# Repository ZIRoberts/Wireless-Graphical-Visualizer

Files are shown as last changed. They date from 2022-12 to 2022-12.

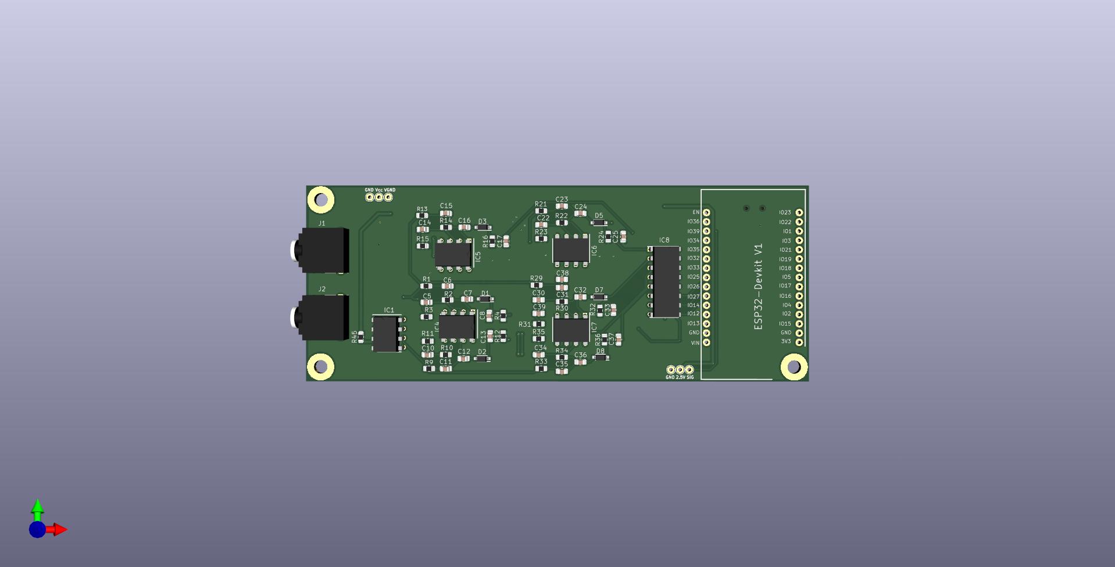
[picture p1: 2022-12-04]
Graphic Equalizer/Graphic_Equalzier_Schematic.jpg

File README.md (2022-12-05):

# Wireless-Graphical-Visualizer
Maintain all documents relating to the creation of the Realtime Wireless Graphical Equalizer.  All symbols, schematics, footprints, and board layouts are designed in KiCad.

Top Orth

# Overview

There is a single board in this sytem and it is broken up into three sections represented by their own respeitive schematic sheet. The first section is the board's inputs. This includes the audio input, power input and regulation, and the audio isolation buffer. Audio is input by a standard 3.5 mm audio cable through one of the two linked audio jacks and enters the system by passing through the unity gain isolation buffer. The two audio jacks are to allow for the user to pass the audio through the device to a speaker without any disortion caused by the filters. Power is inputed by a standard USB Type-B mini cable. There are two 2.5 V linear regulators connected directly to the input line. One serves as a virtual ground to refence the audio signal two later in on in the single supply band pass filters. The other is used on the output of the filters as a voltage calmp to ensure the microcontroller will not get damaged due to an unexpectedly large singal being passed through the filters.

The second section is the bandpass filter section. There are 8 multiple feedback band pass filters. Multifple feed back band pass fitlers were selected based on their low componet cost, moderate gain, and able to handle to filter a signal up to around 5 Q. The 8 bands are tuned to the fallowing frequnecies: 160, 250, 400, 800, 1000, 2500, 4000, and 6500 Hz. The frequncies are filted through their specified filter, have their DC offset stripped, pass through a half-wave rectifer and a 22 uF capacitor to keep the signal from instantly dissapating. This output is then passed through a voltage clamp consiting of a 2.5 V linear regulator and a 500 mV foward voltage diode to prevent the output signal from passive above 3 V as any input above 3V3 would fry the microcontroller. 

The third section is the microcontoller and multiplexor. This section cotnains the connections for the selected ESP32 microcontroller along with the mux. The mux is used to select which of the 8 filtered outputs would be read in by the microcontroller. The MCU used for this project is the ESP32 by Espressiff Systems. This microcontroller was sekected because it was of appropriate size, had appropriate pin count, built in wireless communication, compatablity with Arduino libraries, and the creator already had experience using this family of microcontrollers. This sheet also holds the diodes used for the voltage clamp discribed on in the previous section.

A full list of electronic components can be found in the Bill of Materials.xlsx and images of the design can be found below.

# Schematic
## Aduio and Power Sheet
Input and power sheet
## Bandpass Filter Sheet
Band Pass filter stage
## Microcontroller sheet
microcontroller, mux, Vclamp

# PCB Layout
## Front Copper 
front copper
## Back Copper
Back copper

# 3D Renders
## Front Render
top render
## Bottom Render
bottom render

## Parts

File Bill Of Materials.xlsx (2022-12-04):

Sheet: Mouser
Part Type | Part # | val | Package | quanity per | quanity purchase | price purchase | price per board | Total | link
Audio Jack | SJ1-3523N | x |  | 2 | 4 | $0.74 | $1.48 | $2.96 | https://www.mouser.com/ProductDetail/CUI-Devices/SJ1-3523N?qs=WyjlAZoYn50aNl0vAhb3Tg%3D%3D
usb terminal | 10033526-N3212LF | x | smd | 1 | 5 | $0.77 | $0.77 | $3.85 | https://www.mouser.com/ProductDetail/Amphenol-FCI/10033526-N3212LF
Duel Op amp | TLV2372IP | x | dip 8 | 4 | 10 | $2.39 | $9.56 | $23.90 | https://www.mouser.com/ProductDetail/Texas-Instruments/TLV2372IP?qs=dQbkqP7qjabLXs2c4TTU4Q%3D%3D
Single op amp | TLV2371IP | x | dip 8 | 1 | 4 | $1.87 | $1.87 | $7.48 | https://www.mouser.com/ProductDetail/Texas-Instruments/TLV2371IP?qs=5WY7Uqh921z4LbFYVLVHkQ%3D%3D
mux | MAX4617CPE+ | x | dip 16 | 1 | 3 | $4.80 | $4.80 | $14.40 | https://www.mouser.com/ProductDetail/Maxim-Integrated/MAX4617CPE%2b
voltage reg | MCP1700T-2502E/TT | 2.5V | sot-23-3 | 2 | 6 | $0.41 | $0.82 | $2.46 | https://www.mouser.com/ProductDetail/Microchip-Technology/MCP1700T-2502E-TT?qs=fM4xO01eazNo%2FPEFFkh6Nw%3D%3D
IC Socket | 110-41-308-41-001000 | x | dip 8 | 5 | 10 | $0.56 | $2.80 | $5.60 | https://www.mouser.com/ProductDetail/Mill-Max/110-41-308-41-001000?qs=dvxwXVM4mZVj1CY1TePuww%3D%3D
female header | 15Fx1-254mm | x | header | 2 | 6 | $1.04 | $2.08 | $6.24 | https://www.mouser.com/ProductDetail/Gravitech/15Fx1-254mm?qs=Vxac6xGyzPnMG7UJxd5xkg%3D%3D
screw terminal | 1935161 | x | 1x10 | 2 | 2 | $0.49 | $0.98 | $0.98 | https://www.mouser.com/ProductDetail/Phoenix-Contact/1935161?qs=W3wJikR1%252BS6eKzfFl8Rbew%3D%3D
schottky diode | BAT54W-HG3-18 | 200 mv Vf | SOD-123-2 | 8 | 20 | $0.24 | $1.90 | $4.74 | https://www.mouser.com/ProductDetail/Vishay-Semiconductors/BAT54W-HG3-18?qs=BJlw7L4Cy79w8lzctLBe5g%3D%3D
schottky diode | MMBD101LT1G | 600 mv Vf | sot-23-3 | 8 | 20 | $0.20 | $1.59 | $3.98 | https://www.mouser.com/ProductDetail/ON-Semiconductor/MMBD101LT1G
Capacitor | C0805C103J5RACTU | .01u | 0805 | 12 | 30 | $0.05 | $0.55 | $1.38 | https://www.mouser.com/ProductDetail/KEMET/C0805C103J5RACTU?qs=Onq5MIl0ZjiJ615hCkQQ7A%3D%3D
Capacitor | 08055C203JAT4A | .02u | 0805 | 4 | 10 | $0.25 | $1.00 | $2.51 | https://www.mouser.com/ProductDetail/AVX/08055C203JAT4A?qs=ykEKLGTiBcxBcZNPbEjGfw%3D%3D | cheaper to double up on .01 u
Capacitor | 08055C104JAT2A | .1u | 0805 | 9 | 25 | $0.09 | $0.82 | $2.27 | https://www.mouser.com/ProductDetail/AVX/08055C104JAT2A?qs=rjW0lv%2FNY4O5UTQV%252BL9pEw%3D%3D
Capacitor | CL21B224KAFNNNG | .22u | 0805 | 5 | 15 | $0.03 | $0.17 | $0.51 | https://www.mouser.com/ProductDetail/Samsung-Electro-Mechanics/CL21B224KAFNNNG
Capacitor | CL21A106KPCLQNC | 10u | 0805 | 8 | 20 | $0.05 | $0.39 | $0.98 | https://www.mouser.com/ProductDetail/Samsung-Electro-Mechanics/CL21A106KPCLQNC?qs=j0anFx7zyhyh2SZCFuTXeg%3D%3D
Capacitor | GRM21BR61A226ME51L | 22u | 0805 | 8 | 20 | $0.13 | $1.06 | $2.64 | https://www.mouser.com/ProductDetail/Murata-Electronics/GRM21BR61A226ME51L?qs=GJ9CiehniqLndbYAzpHGvw%3D%3D
Capacitor | C0805C105K4RACTU | 1u | 0805 | 6 | 16 | $0.06 | $0.34 | $0.91 | https://www.mouser.com/ProductDetail/KEMET/C0805C105K4RACTU?qs=yrVqjCObULOefkidH6lLLQ%3D%3D
resistor | RC0805JR-100RL | 0 | 0805 | 20 | 100 | $0.01 | $0.30 | $1.50 | https://www.mouser.com/ProductDetail/YAGEO/RC0805JR-100RL?qs=fRxXYNj8ftFe%252BcsxoUmr4g%3D%3D
resistor | ERJ-P06F2700V | 267 | 0805 | 6 | 15 | $0.14 | $0.83 | $2.08 | https://www.mouser.com/ProductDetail/Panasonic/ERJ-P06F2700V?qs=iIVTEDlrHA0KQ7C%252Bd58SjQ%3D%3D
resistor | ERJ-P06F3000V | 301 | 0805 | 1 | 5 | $0.18 | $0.18 | $0.90 | https://www.mouser.com/ProductDetail/Panasonic/ERJ-P06F3000V?qs=iIVTEDlrHA3O1TU1AmFELg%3D%3D
resistor | ERJ-P06F3480V | 348 | 0805 | 1 | 4 | $0.18 | $0.18 | $0.72 | https://www.mouser.com/ProductDetail/Panasonic/ERJ-P06F3480V?qs=iIVTEDlrHA2Mos3Mjm8zhw%3D%3D
resistor | ERJ-P06F4020V | 402 | 0805 | 2 | 6 | $0.20 | $0.40 | $1.20 | https://www.mouser.com/ProductDetail/Panasonic/ERJ-P06F4020V
resistor | ERJ-P06F8060V | 806 | 0805 | 1 | 4 | $0.20 | $0.20 | $0.80 | https://www.mouser.com/ProductDetail/Panasonic/ERJ-P06F8060V
resistor | RC0805FR-101K2L | 1200 | 0805 | 1 | 4 | $0.10 | $0.10 | $0.40 | https://www.mouser.com/ProductDetail/YAGEO/RC0805FR-101K2L?qs=g6xwsc4j%252B%2FqKMlZ4Dwe6Dw%3D%3D
resistor | AC0805FR-7W2KL | 2000 | 0805 | 2 | 10 | $0.06 | $0.12 | $0.59 | https://www.mouser.com/ProductDetail/YAGEO/AC0805FR-7W2KL
resistor | ERJ-P06F4751V | 4750 | 0805 | 1 | 4 | $0.28 | $0.28 | $1.12 | https://www.mouser.com/ProductDetail/Panasonic/ERJ-P06F4751V?qs=iIVTEDlrHA1dktajbqD0%2FQ%3D%3D
resistor | ERJ-P06F4991V | 4990 | 0805 | 1 | 4 | $0.20 | $0.20 | $0.80 | https://www.mouser.com/ProductDetail/Panasonic/ERJ-P06F4991V?qs=sGAEpiMZZMtlubZbdhIBIK7FbVYKWV6WU1u7RLCIVSI%3D
resistor | RCS06036K04FKEA | 6040 | 0805 | 2 | 5 | $0.15 | $0.30 | $0.75 | https://www.mouser.com/ProductDetail/Vishay-Dale/RCS06036K04FKEA?qs=6AVTNucw1PVOKD11i3Bl8Q%3D%3D
resistor | ERJ-P06F7501V | 7500 | 0805 | 2 | 10 | $0.15 | $0.31 | $1.54 | https://www.mouser.com/ProductDetail/Panasonic/ERJ-P06F7501V
resistor | RC0805FR-1310KL | 10000 | 0805 | 2 | 10 | $0.03 | $0.06 | $0.31 | https://www.mouser.com/ProductDetail/YAGEO/RC0805FR-1310KL?qs=m6lXFsvg5e2DzD%2FscmphNQ%3D%3D
resistor | ERJ-6ENF2372V | 23700 | 0805 | 2 | 10 | $0.07 | $0.15 | $0.75 | https://www.mouser.com/ProductDetail/Panasonic/ERJ-6ENF2372V?qs=50QC8w71jAvtfOjSV7AQZw%3D%3D
resistor | CR0805-FX-3482ELF | 34800 | 0805 | 1 | 10 | $0.05 | $0.05 | $0.50 | https://www.mouser.com/ProductDetail/Bourns/CR0805-FX-3482ELF?qs=TYKCbaKwe1BX%252B2fT1xNjLQ%3D%3D
resistor | ERJ-6ENF3572V | 35700 | 0805 | 1 | 4 | $0.10 | $0.10 | $0.40 | https://www.mouser.com/ProductDetail/Panasonic/ERJ-6ENF3572V
resistor | ERJ-P06F4022V | 40200 | 0805 | 1 | 4 | $0.20 | $0.20 | $0.80 | https://www.mouser.com/ProductDetail/Panasonic/ERJ-P06F4022V?qs=iIVTEDlrHA1ZhEwjw363Sg%3D%3D
resistor | RC0805FR-1347K5L | 47500 | 0805 | 1 | 25 | $0.02 | $0.02 | $0.47 | https://www.mouser.com/ProductDetail/YAGEO/RC0805FR-1347K5L?qs=m6lXFsvg5e1D72C5kBh1CA%3D%3D
resistor | AC0805FR-7W49K9L | 49900 | 0805 | 2 | 10 | $0.06 | $0.12 | $0.59 | https://www.mouser.com/ProductDetail/YAGEO/AC0805FR-7W49K9L?qs=mQk0km4IMDeRJfAtVBkHxg%3D%3D
resistor | ERJ-UP3F5492V | 54900 | 0805 | 1 | 4 | $0.26 | $0.26 | $1.04 | https://www.mouser.com/ProductDetail/Panasonic/ERJ-UP3F5492V?qs=GedFDFLaBXFu8CUGA65Aag%3D%3D
resistor | AC0805FR-7W100KL | 100000 | 0805 | 8 | 20 | $0.08 | $0.67 | $1.68 | https://www.mouser.com/ProductDetail/YAGEO/AC0805FR-7W100KL?qs=mQk0km4IMDdDYiNYyM1r7w%3D%3D
resistor | RC0805FR-13200KL | 200k | 0805 | 3 | 10 | $0.04 | $0.14 | $0.45 | https://www.mouser.com/ProductDetail/YAGEO/RC0805FR-13200KL?qs=m6lXFsvg5e0hZfOOUQ%2FIgw%3D%3D
resistor | ERJ-P06F2553V | 255k | 0805 | 3 | 10 | $0.15 | $0.46 | $1.54 | https://www.mouser.com/ProductDetail/Panasonic/ERJ-P06F2553V?qs=iIVTEDlrHA22vnXhPU7c3w%3D%3D
resistor | ERJ-P06F3653V | 365k | 0805 | 1 | 4 | $0.18 | $0.18 | $0.72 | https://www.mouser.com/ProductDetail/Panasonic/ERJ-P06F3653V?qs=iIVTEDlrHA0ZFGDvIdekGA%3D%3D
resistor | RC0805FR-101ML | 1M | 0805 | 8 | 20 | $0.03 | $0.25 | $0.62 | https://www.mouser.com/ProductDetail/YAGEO/RC0805FR-101ML?qs=g6xwsc4j%252B%2FquvT%252BzGahIFg%3D%3D
 |  |  | Component | 162 | 538 |  |  | $8.00 | shipping
 |  |  |  |  |  |  | $39.04 | $118.08
 |  |  | resistor | 74
 |  |  | Caps | 52
Dev board | Esp32 S3 N8R8 |  |  |  | 2 | $15.00 |  | $30.00 | https://www.mouser.com/ProductDetail/Espressif-Systems/ESP32-S3-DevKitC-1-N8R8

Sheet: Led & PCB pricing
Item | price | description | link
LED | 25.99 | ws2812B 60 pix/m leds | https://www.amazon.com/BTF-LIGHTING-Individual-Addressable-300Pixels-Waterproof/dp/B088B9QWHT?s=hi
power supply | 23.99 | 5v 10 amp 50w power supply | https://www.amazon.com/ALITOVE-Transformer-Converter-5-5x2-1mm-100V-240V/dp/B0852HL336
PCB | 68.8 | PCB | https://www.digikey.com/en/resources/dkred
usb power cable | 5.14 | mcro type B calbe | https://www.amazon.com/Monoprice-10-Feet-Mini-B-Ferrite-105449/dp/B002KL8J8W
Solder | 5.93 | kester leaded solder | https://www.amazon.com/Kester-83-4000-0000-SN60PB40-Solder-Diameter/dp/B00068IJNQ
Flux | 9 | rosin flux | https://www.amazon.com/SRA-Rosin-Paste-Flux-135/dp/B008ZIV85A/ref=cm_cr_arp_d_product_top?ie=UTF8
Solder wick | 9.74 |  | https://www.amazon.com/NTE-Electronics-SW02-10-No-Clean-Blue-098/dp/B0195UVWJ8
Tweezers | 6 |  | https://www.amazon.com/Precision-Anti-Static-Electronics-Sodlering%EF%BC%8CJewelry-Laboratory/dp/B07ZBZ7MSF
total | 154.59
OVER ALL TOTAL | 272.667

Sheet: power consumption (amps)
Component | Current (mA) | Quanity | Total Current
Esp32 | 240 | 1 | 240
Mux | 0.01 | 1 | 0.01
Duel Amp | 1.1 | 6 | 6.6
Single Amp | 0.55 | 1 | 0.55
Voltage reg | 2 | 2 | 4
 |  | Typical | 251.16
 |  | Inrush current | 753.48
 | USB TERMINAL SUPPLY |  | 1800

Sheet: Component mapping
Resistor |  |  |  | Capacitor |  |  | Diode |  |  |  | IC |  |  | Other
Value | Quanity | Mapping |  | Value | Quanity | Mapping | Value | Quanity | Mapping |  | Part | Quanity | Mapping | Type | Quanity | Mapping
0 | 20 | r5/r6 |  | .01u | 12 | C5,C6,C10,C11, C8,C13,C17,C21, C25,C29,C33,C37 | 200 mv Vf | 8 | D1, D2, D3, D4, D5, D6, D7, D8 |  | Single op amp | 4 | IC4, IC5, IC6, IC7 | Audio Jack | 2 | j1, j2
270 | 3 | R3, R23, R31 |  | .02u | 4 | C14,C15,C19,C20 | 600 mv Vf | 8 | D9, D10, D11, D12, D13, D14, D15, D16 |  | Duel Op amp | 1 | IC1 | usb terminal | 1 | j3
301 | 1 | R15 |  | .1u | 9 | c9, C22, c23, c26,c27, C30,C31,C38,C39 |  |  |  |  | Vreg 2.5 V | 2 | IC2, IC3 | 8 pin socket | 5 | IC1, IC4, IC5, IC6, IC7
348 | 1 | R11 |  | 10u | 8 | C7, C12, C16, C20, C24, C28, C32, C36 |  |  |  |  | Mux | 1 | IC8 | 16 pin socket | 1 | IC8
402 | 2 | R27, R35 |  | 22u | 8 | C7, C12, C16, C20, C24, C28, C32, C36 |  |  |  |  |  |  |  | 15 pin header | 2 | U1 (esp32)
806 | 1 | R19 |  | 1u | 6 | c1, c2, c3, c4, C34, C35
2000 | 2 | R7,R8
4750 | 1 | R1 |  |  | 47
4990 | 1 | R21
6040 | 1 | R34
7500 | 2 | R13, R25
10000 | 2 | R9, R17 |  |  | FIND VALUE FOR VGND RESISTORS
23700 | 2 | R2, R22 |  |  | 0ohm or 47500 |  |  |  |  | 26525.82385 | 0.1612903226 | 0.2903225806
34800 | 1 | r14 |  |  | R37, R38, R39, R40, R41, R42, R43, R44
35700 | 1 | R30
40200 | 1 | R26
47500 | 1 | R10
49900 | 2 | R7,R8 | Changed to 100k
54900 | 1 | R18
100000 | 8 | R4,R12,R16,R20, R24,R28,R32,R36
1M | 8 | R4,R12,R16,R20, R24,R28,R32,R36
DNP | 3 | R46, R47, R5/R6
 | 62
IMPROVEING RECTIFIER
 | Resistor |  |  |  | Capacitor |  |  | Diode
Value | Quanity | Mapping |  | Value | Quanity | Mapping | Value | Quanity | Mapping
267 | 1 | R2 |  | .22u | 5 | C37, C33, C29, C25, C21 | 200mv | 8 | N/A
1200 | 1 | R1
6040 | 1 | R5
200k | 2 | R20, R24
255k | 2 | R28, R32
365k | 1 | R36
 |  |  | https://www.mouser.com/ProductDetail/Samsung-Electro-Mechanics/CL21B224KAFNNNG
 |  |  | https://www.mouser.com/ProductDetail/YAGEO/AC0805FR-7W100KL?qs=mQk0km4IMDdDYiNYyM1r7w%3D%3D
 |  |  | https://www.mouser.com/ProductDetail/Nexperia/BAT54GWJ?qs=EO%252B2iqeaG03qzVr9l4ml1Q%3D%3D
 |  |  | https://www.mouser.com/c/semiconductors/discrete-semiconductors/diodes-rectifiers/schottky-diodes-rectifiers/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
 |  |  | https://www.mouser.com/ProductDetail/Panjit/BAT54C_R1_00001?qs=sPbYRqrBIVlWgFH05T87cA%3D%3D
 |  |  | https://www.mouser.com/datasheet/2/1057/BAT54_SERIES-1868856.pdf
 |  |  | https://www.digikey.com/en/products/filter/diodes-rectifiers-single/280
 |  |  | https://www.digikey.com/en/products/detail/vishay-general-semiconductor-diodes-division/BAT54W-G3-08/4830241

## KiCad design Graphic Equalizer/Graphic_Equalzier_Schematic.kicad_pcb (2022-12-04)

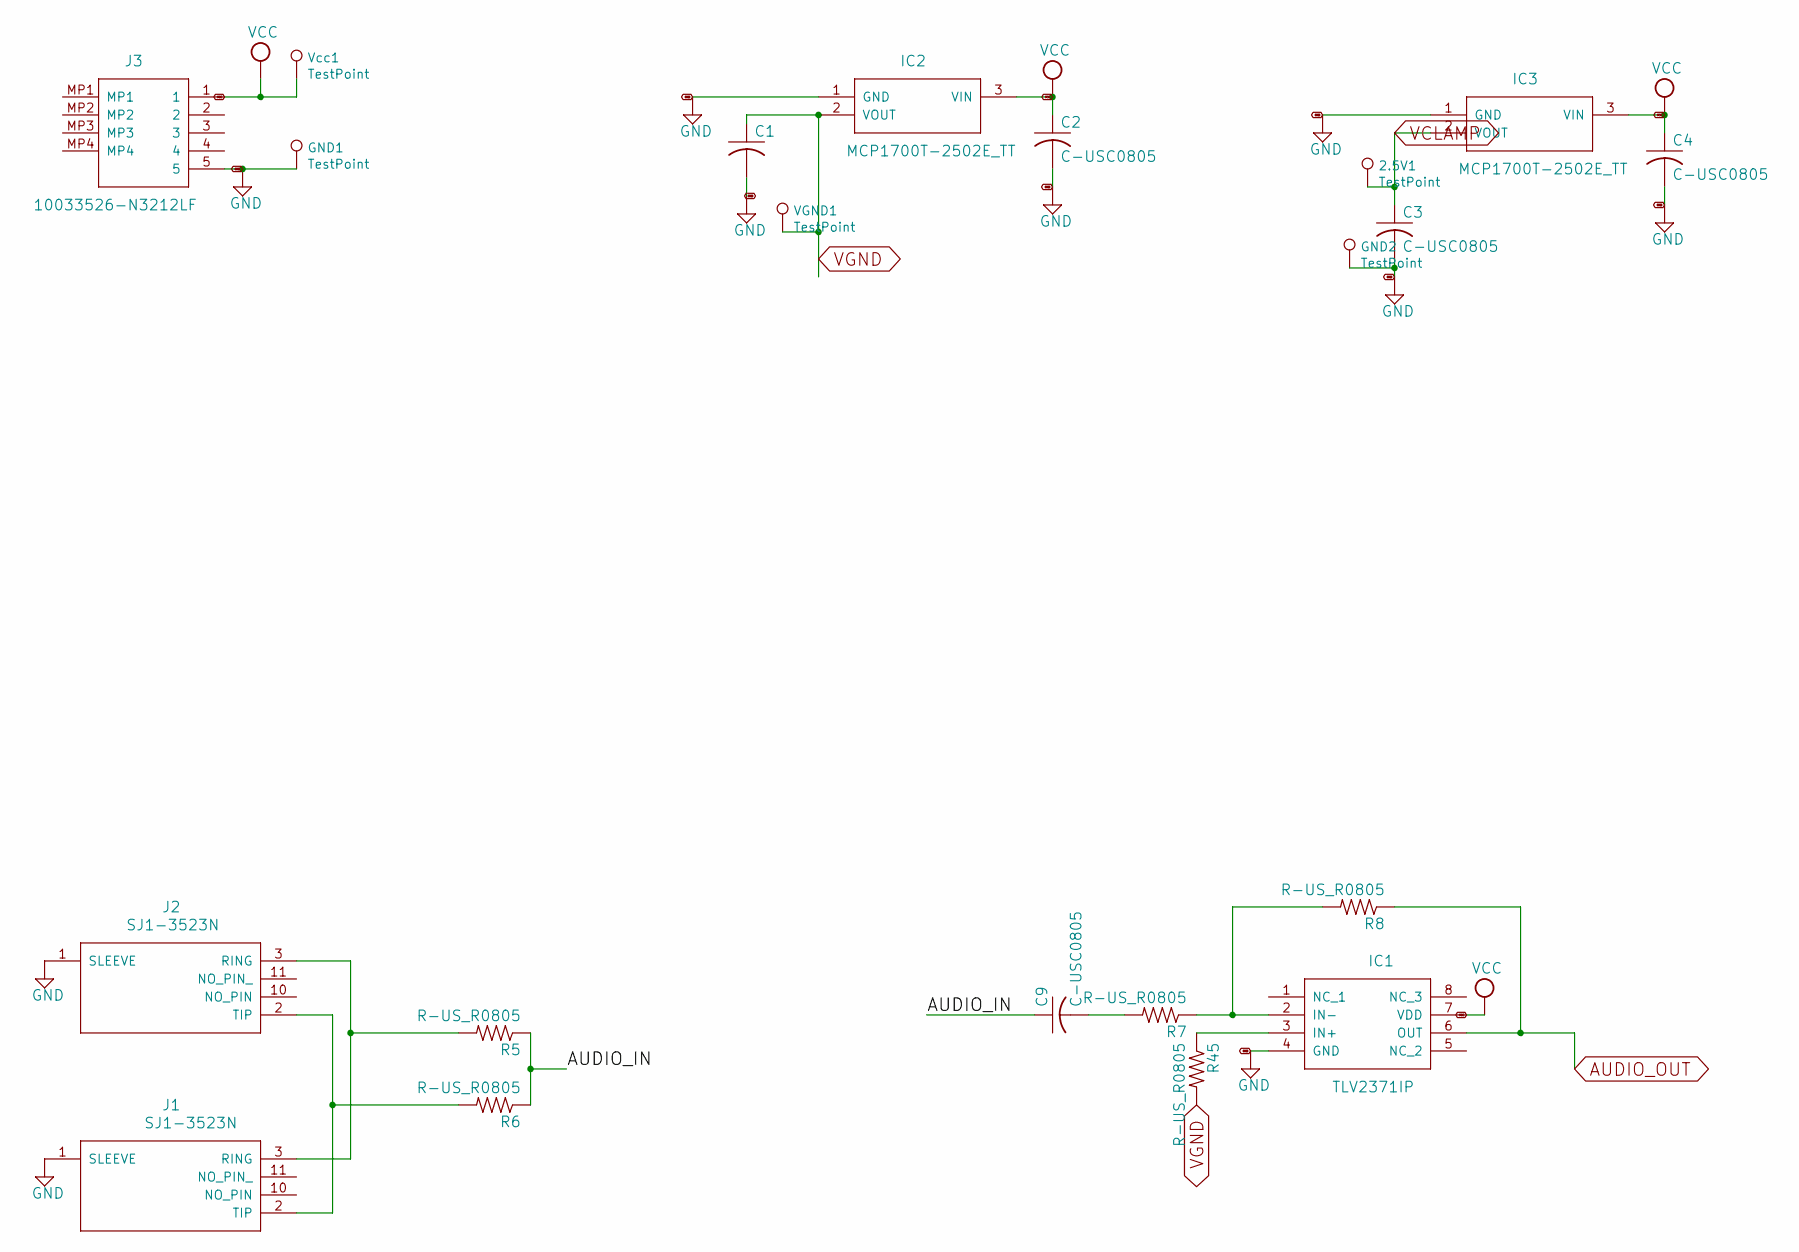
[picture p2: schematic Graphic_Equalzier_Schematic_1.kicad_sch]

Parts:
2.5V1: TestPoint; TestPoint_THTPad_D2.0mm_Drill1.0mm
C1, C2, C3, C4, C9: C-USC0805; C0805
GND1, GND2: TestPoint; TestPoint_THTPad_D2.0mm_Drill1.0mm
IC1: TLV2371IP; DIP794W53P254L959H508Q8N
IC2, IC3: MCP1700T-2502E_TT; SOT95P237X112-3N
J1, J2: SJ1-3523N; SJ13523N
J3: 10033526-N3212LF; 10033526N3212LF
R5, R6, R7, R8, R45: R-US_R0805; R0805
VGND1: TestPoint; TestPoint_THTPad_D2.0mm_Drill1.0mm
Vcc1: TestPoint; TestPoint_THTPad_D2.0mm_Drill1.0mm

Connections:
/Graphic_Equalzier_Schematic_1/AUDIO_IN: C9.1, R5.1, R6.1
AUDIO_OUT: IC1.6 (OUT), R8.1; also elsewhere on the board
GND: C1.2, C2.2, C3.2, C4.2, GND1.1, GND2.1, IC1.4 (GND), IC2.1 (GND), IC3.1 (GND), J1.1 (SLEEVE), J2.1 (SLEEVE), J3.5; also elsewhere on the board
unnamed: C9.2, R7.2
unnamed: IC1.2 (IN-), R7.1, R8.2
unnamed: IC1.3 (IN+), R45.1
unnamed: J1.2 (TIP), J2.2 (TIP), R6.2
unnamed: J1.3 (RING), J2.3 (RING), R5.2
VCC: C2.1, C4.1, IC1.7 (VDD), IC2.3 (VIN), IC3.3 (VIN), J3.1, Vcc1.1; also elsewhere on the board
VCLAMP: 2.5V1.1, C3.1, IC3.2 (VOUT); also elsewhere on the board
VGND: C1.1, IC2.2 (VOUT), R45.2, VGND1.1; also elsewhere on the board

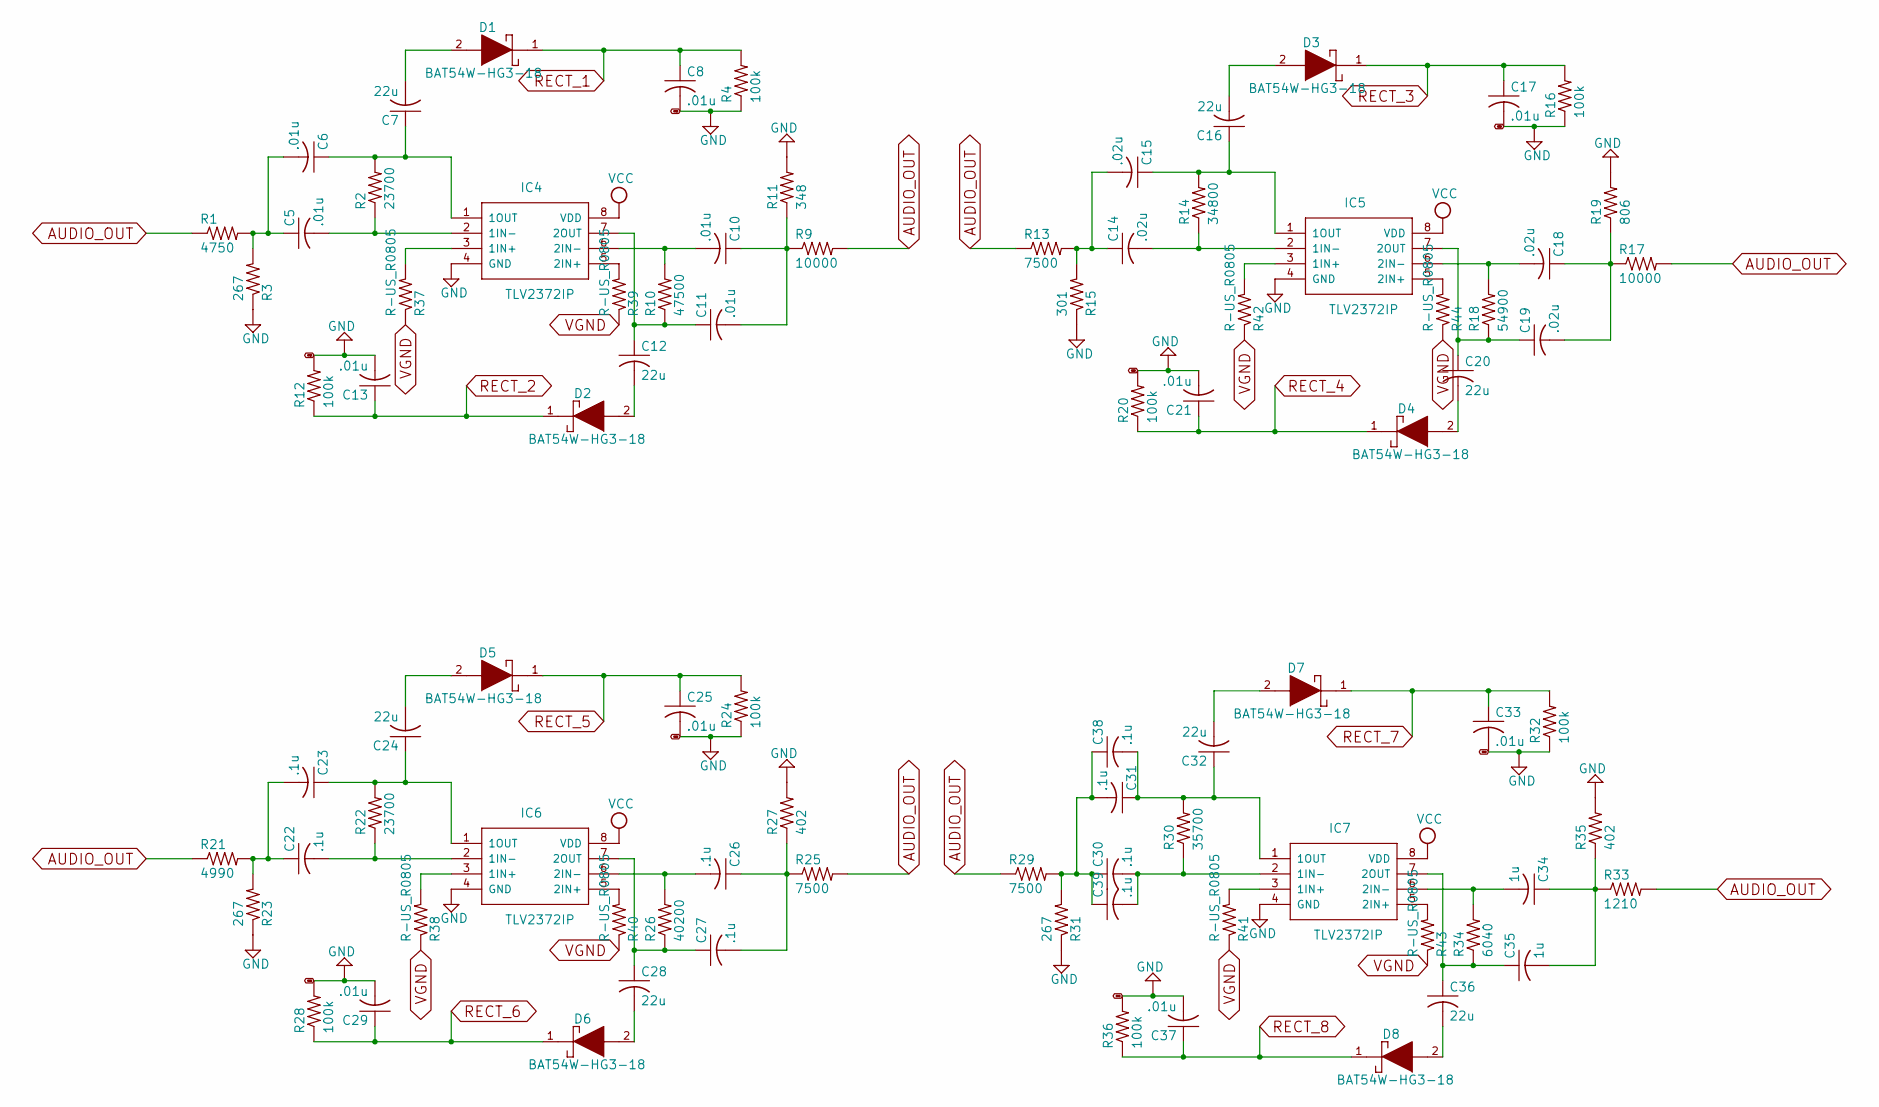
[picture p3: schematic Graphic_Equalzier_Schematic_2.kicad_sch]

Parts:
C5, C6, C8, C10, C11, C13, C17, C21, C25, C29, C33, C37: .01u; C0805
C7, C12, C16, C20, C24, C28, C32, C36: 22u; C0805
C14, C15, C18, C19: .02u; C0805
C22, C23, C26, C27, C30, C31, C38, C39: .1u; C0805
C34, C35: 1u; C0805
D1, D2, D3, D4, D5, D6, D7, D8: BAT54W-HG3-18; SOD3716X135N
IC4, IC5, IC6, IC7: TLV2372IP; DIP794W53P254L959H508Q8N
R1: 4750; R0805
R2, R22: 23700; R0805
R3, R23, R31: 267; R0805
R4, R12, R16, R20, R24, R28, R32, R36: 100k; R0805
R9, R17: 10000; R0805
R10: 47500; R0805
R11: 348; R0805
R13: 7500; R_0805_2012Metric_Pad1.20x1.40mm_HandSolder
R14: 34800; R0805
R15: 301; R0805
R18: 54900; R0805
R19: 806; R0805
R21: 4990; R0805
R25, R29: 7500; R0805
R26: 40200; R0805
R27, R35: 402; R0805
R30: 35700; R0805
R33: 1210; R0805
R34: 6040; R0805
R37, R38, R39, R40, R41, R42, R43, R44: R-US_R0805; R0805

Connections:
AUDIO_OUT: R1.1, R9.2, R13.1, R17.2, R21.1, R25.2, R29.1, R33.2; also elsewhere on the board
GND: C8.2, C13.2, C17.2, C21.2, C25.2, C29.2, C33.2, C37.2, IC4.4 (GND), IC5.4 (GND), IC6.4 (GND), IC7.4 (GND), R3.1, R4.1, R11.2, R12.2, R15.1, R16.1, R19.2, R20.2, R23.1, R24.1, R27.2, R28.2, R31.1, R32.1, R35.2, R36.2; also elsewhere on the board
unnamed: C5.1, C6.2, R1.2, R3.2
unnamed: C5.2, IC4.2 (1IN-), R2.1
unnamed: C6.1, C7.1, IC4.1 (1OUT), R2.2
unnamed: C7.2, D1.2 (A)
unnamed: C10.1, C11.2, R9.1, R11.1
unnamed: C10.2, IC4.6 (2IN-), R10.2
unnamed: C11.1, C12.1, IC4.7 (2OUT), R10.1
unnamed: C12.2, D2.2 (A)
unnamed: C14.1, C15.2, R13.2, R15.2
unnamed: C14.2, IC5.2 (1IN-), R14.1
unnamed: C15.1, C16.1, IC5.1 (1OUT), R14.2
unnamed: C16.2, D3.2 (A)
unnamed: C18.1, C19.2, R17.1, R19.1
unnamed: C18.2, IC5.6 (2IN-), R18.2
unnamed: C19.1, C20.1, IC5.7 (2OUT), R18.1
unnamed: C20.2, D4.2 (A)
unnamed: C22.1, C23.2, R21.2, R23.2
unnamed: C22.2, IC6.2 (1IN-), R22.1
unnamed: C23.1, C24.1, IC6.1 (1OUT), R22.2
unnamed: C24.2, D5.2 (A)
unnamed: C26.1, C27.2, R25.1, R27.1
unnamed: C26.2, IC6.6 (2IN-), R26.2
unnamed: C27.1, C28.1, IC6.7 (2OUT), R26.1
unnamed: C28.2, D6.2 (A)
unnamed: C30.1, C31.2, C38.1, C39.1, R29.2, R31.2
unnamed: C30.2, C39.2, IC7.2 (1IN-), R30.1
unnamed: C31.1, C32.1, C38.2, IC7.1 (1OUT), R30.2
unnamed: C32.2, D7.2 (A)
unnamed: C34.1, C35.2, R33.1, R35.1
unnamed: C34.2, IC7.6 (2IN-), R34.2
unnamed: C35.1, C36.1, IC7.7 (2OUT), R34.1
unnamed: C36.2, D8.2 (A)
unnamed: IC4.3 (1IN+), R37.2
unnamed: IC4.5 (2IN+), R39.2
unnamed: IC5.3 (1IN+), R42.2
unnamed: IC5.5 (2IN+), R44.2
unnamed: IC6.3 (1IN+), R38.2
unnamed: IC6.5 (2IN+), R40.2
unnamed: IC7.3 (1IN+), R41.2
unnamed: IC7.5 (2IN+), R43.2
RECT_1: C8.1, D1.1 (K), R4.2; also elsewhere on the board
RECT_2: C13.1, D2.1 (K), R12.1; also elsewhere on the board
RECT_3: C17.1, D3.1 (K), R16.2; also elsewhere on the board
RECT_4: C21.1, D4.1 (K), R20.1; also elsewhere on the board
RECT_5: C25.1, D5.1 (K), R24.2; also elsewhere on the board
RECT_6: C29.1, D6.1 (K), R28.1; also elsewhere on the board
RECT_7: C33.1, D7.1 (K), R32.2; also elsewhere on the board
RECT_8: C37.1, D8.1 (K), R36.1; also elsewhere on the board
VCC: IC4.8 (VDD), IC5.8 (VDD), IC6.8 (VDD), IC7.8 (VDD); also elsewhere on the board
VGND: R37.1, R38.1, R39.1, R40.1, R41.1, R42.1, R43.1, R44.1; also elsewhere on the board

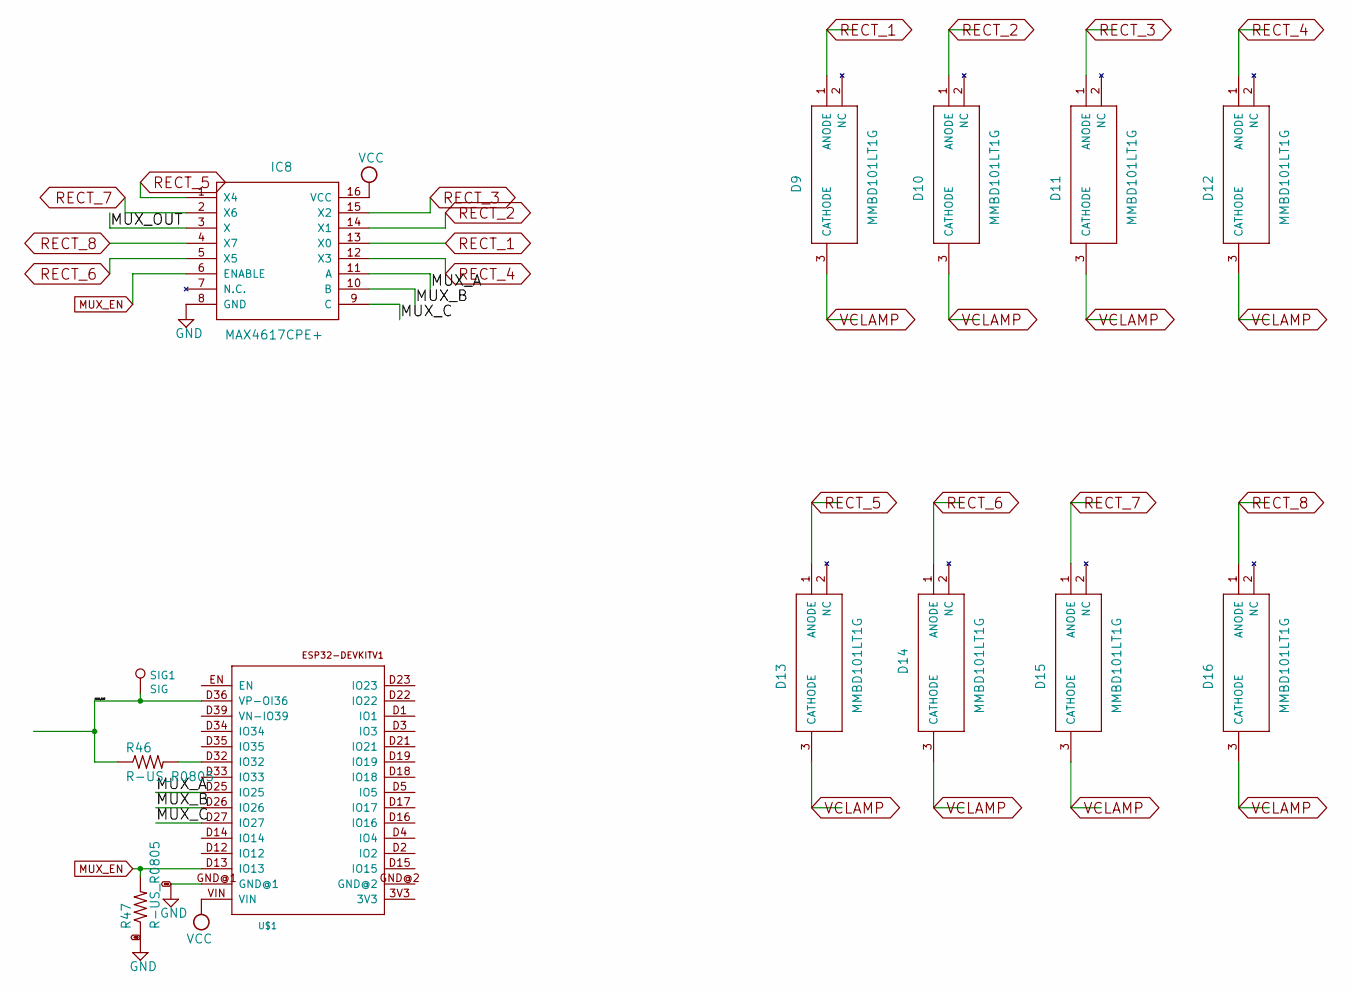
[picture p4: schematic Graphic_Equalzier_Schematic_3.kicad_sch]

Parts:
D9, D10, D11, D12, D13, D14, D15, D16: MMBD101LT1G; SOT96P237X111-3N
IC8: MAX4617CPE+; DIP794W56P254L1918H457Q16N
R46, R47: R-US_R0805; R0805
SIG1: SIG; TestPoint_THTPad_D2.0mm_Drill1.0mm
U$1: ESP32DEVKITV1; ESP32-DEVKITV1

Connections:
/Graphic_Equalzier_Schematic_3/MUX_A: IC8.11 (A), U$1.D25 (IO25)
/Graphic_Equalzier_Schematic_3/MUX_B: IC8.10 (B), U$1.D26 (IO26)
/Graphic_Equalzier_Schematic_3/MUX_C: IC8.9 (C), U$1.D27 (IO27)
/Graphic_Equalzier_Schematic_3/MUX_OUT: IC8.3 (X), R46.1, SIG1.1, U$1.D36 (VP-OI36); also elsewhere on the board
GND: IC8.8 (GND), R47.1, U$1.GND@1; also elsewhere on the board
MUX_EN: IC8.6 (ENABLE), R47.2, U$1.D13 (IO13)
unnamed: R46.2, U$1.D32 (IO32)
RECT_1: D9.1 (ANODE), IC8.13 (X0); also elsewhere on the board
RECT_2: D10.1 (ANODE), IC8.14 (X1); also elsewhere on the board
RECT_3: D11.1 (ANODE), IC8.15 (X2); also elsewhere on the board
RECT_4: D12.1 (ANODE), IC8.12 (X3); also elsewhere on the board
RECT_5: D13.1 (ANODE), IC8.1 (X4); also elsewhere on the board
RECT_6: D14.1 (ANODE), IC8.5 (X5); also elsewhere on the board
RECT_7: D15.1 (ANODE), IC8.2 (X6); also elsewhere on the board
RECT_8: D16.1 (ANODE), IC8.4 (X7); also elsewhere on the board
VCC: IC8.16 (VCC), U$1.VIN; also elsewhere on the board
VCLAMP: D9.3 (CATHODE), D10.3 (CATHODE), D11.3 (CATHODE), D12.3 (CATHODE), D13.3 (CATHODE), D14.3 (CATHODE), D15.3 (CATHODE), D16.3 (CATHODE); also elsewhere on the board

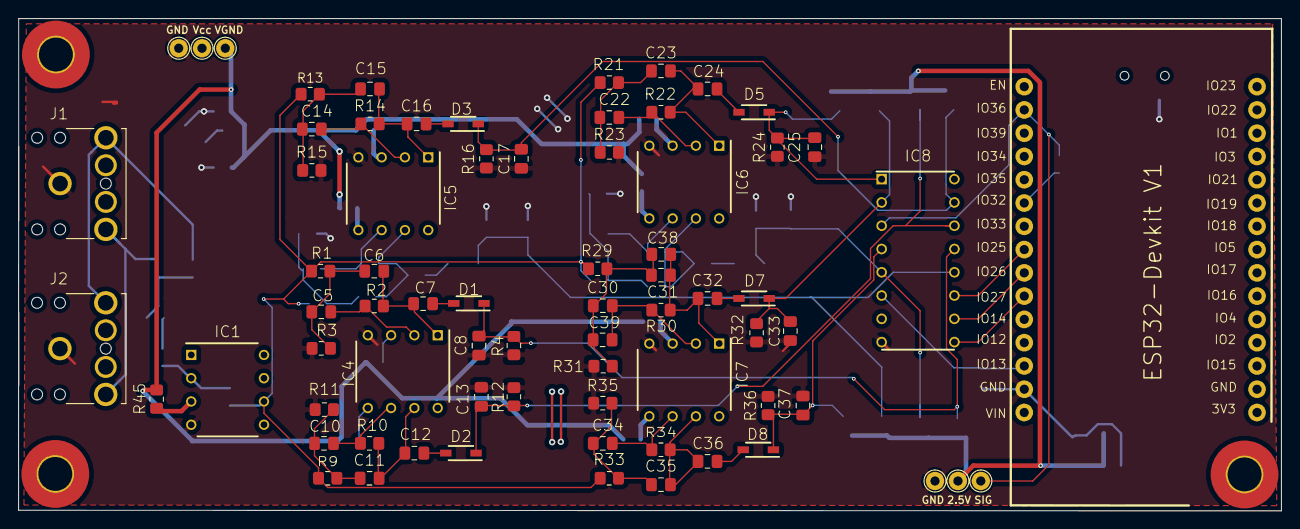
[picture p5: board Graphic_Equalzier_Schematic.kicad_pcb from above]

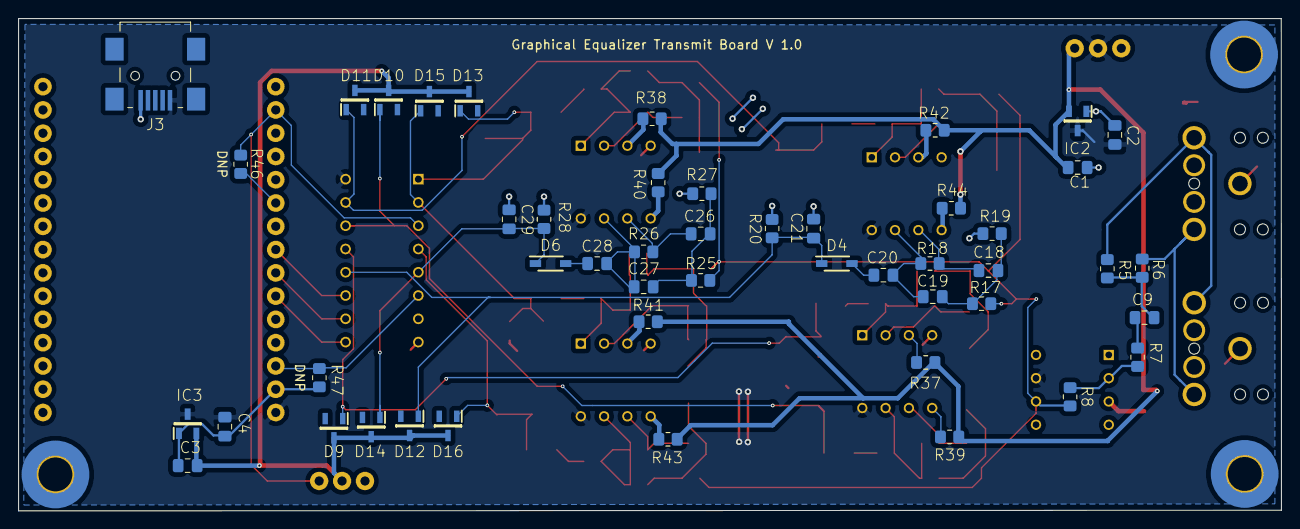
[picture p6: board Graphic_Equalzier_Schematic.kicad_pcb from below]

Board: 2 copper layers, 137.8 x 53.7 mm, 123 parts (48 on the bottom side), 65 nets.

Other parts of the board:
2.5V: TestPoint; TestPoint_THTPad_D2.0mm_Drill1.0mm
 : MountingHole_3.7mm_Pad_TopBottom
 #2,  #3: MountingHole_3.7mm_Pad_TopBottom
GND: TestPoint; TestPoint_THTPad_D2.0mm_Drill1.0mm
GND#2: TestPoint; TestPoint_THTPad_D2.0mm_Drill1.0mm
SIG: SIG; TestPoint_THTPad_D2.0mm_Drill1.0mm
VGND: TestPoint; TestPoint_THTPad_D2.0mm_Drill1.0mm
Vcc: TestPoint; TestPoint_THTPad_D2.0mm_Drill1.0mm

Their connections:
/Graphic_Equalzier_Schematic_3/MUX_OUT: SIG.1; also elsewhere on the board
GND: GND.1, GND#2.1; also elsewhere on the board
VCC: Vcc.1; also elsewhere on the board
VCLAMP: 2.5V.1; also elsewhere on the board
VGND: VGND.1; also elsewhere on the board
